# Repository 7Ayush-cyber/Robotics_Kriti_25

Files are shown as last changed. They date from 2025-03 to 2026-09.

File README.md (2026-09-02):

# Smart Disposable Dustbin — Robotics Kriti '25 🏆

**Gold Medal Winner, Kriti (Robotics Competition), 2025**

An automated waste management system that combines sensor-based waste segregation, vacuum-powered plastic bag deployment, and CNC-controlled mechanisms to make waste disposal more efficient, hygienic, and hands-free.

## Overview

The Smart Disposable Dustbin automates the full waste-handling cycle — detecting waste, opening the lid, segregating it, compacting it, and deploying a fresh plastic liner — with minimal manual intervention. The system integrates ultrasonic distance/level sensing, gas sensing, a BLDC fan for vacuum-based bag handling, and a stepper-motor-driven CNC mechanism, all coordinated through an Arduino Mega.

## Key Features

- **Automatic lid operation** — opens/closes based on proximity detection, reducing manual contact and improving hygiene
- **Sensor-based level detection** — ultrasonic sensors monitor fill level to know when the bin needs attention
- **Gas sensing** — detects buildup of harmful/foul gases inside the bin
- **Vacuum-powered bag deployment** — a BLDC fan is used to unfurl and seat a new plastic bag automatically after disposal
- **CNC-controlled compaction mechanism** — a stepper-motor-driven system compacts waste and manages the mechanical sequencing of the bin
- **Reduced manual effort** — minimizes the need for a person to touch the bin, its lid, or the liner

## Repository Contents

| Category | Files |
|---|---|
| **Firmware (Arduino)** | `MainMega.ino` (main controller), `sensors.ino`, `lid_opening.ino`, `New_bag_deployment.ino`, `Level_Detection_CNC.ino` |
| **CAD Assemblies** | `Assem1.SLDASM`, `dustbin.SLDASM`, `dustbin_2.SLDASM`, `Plastic_wrapper_assembly.SLDASM` |
| **CAD Parts** | Individual `.SLDPRT` files for structural components — walls, base, lid, motor mounts, compactor walls, plastic holder/wrapper parts, etc. |
| **Engineering Drawings** | `.SLDDRW` drawing files with corresponding `.DXF` exports for manufacturing/laser-cutting |
| **Sheet Metal Data** | `.yld` files (SolidWorks sheet metal flat-pattern data) |
| **Reports** | `Report_Smart_disposable_dustbin.pdf`, `robotics_kriti_final_report.pdf` |

## Hardware Used

- Arduino Mega (main controller)
- Ultrasonic sensors (level/proximity detection)
- Gas sensor
- BLDC fan (vacuum-powered bag deployment)
- Stepper motor (CNC-controlled compaction/actuation)

## Getting Started

### Mechanical
1. Open the assembly files (`Assem1.SLDASM`, `dustbin.SLDASM`, etc.) in SolidWorks to review the full CAD model.
2. Use the corresponding `.DXF` files to laser-cut or CNC-machine the sheet metal/plastic parts.
3. Assemble per the drawings in the `.SLDDRW` files.

### Electronics / Firmware
1. Wire the ultrasonic sensors, gas sensor, BLDC fan, and stepper motor to the Arduino Mega as referenced in the `.ino` files.
2. Upload `MainMega.ino` as the primary control program (it coordinates the subsystem logic found in `sensors.ino`, `lid_opening.ino`, `New_bag_deployment.ino`, and `Level_Detection_CNC.ino`).
3. Power on and test each subsystem (lid actuation, level detection, bag deployment) individually before full integration.

## Documentation

For the complete design rationale, methodology, and results, see:
- `Report_Smart_disposable_dustbin.pdf`
- `robotics_kriti_final_report.pdf`

## Acknowledgment

This project was built for **Kriti**, where it won the **Gold Medal**. This repository is forked from [7Ayush-cyber/Robotics_Kriti_25](https://github.com/7Ayush-cyber/Robotics_Kriti_25).

## License

No license file is currently included. Add one (e.g., MIT) if you intend for others to reuse this work.

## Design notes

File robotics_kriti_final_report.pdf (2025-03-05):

# Smart Disposal Machine

## Organizer: Robotics Club

## Kriti 2025

# Final Submission Report

# ____________________________________

Smart Disposal Machine

## Contents:

1 Abstract | 2
2 Problem Understanding | 2
3 Approach | 3
3.1 Electronics | 3
3.1.1 Lid opening | 3
3.1.2 New bag deployment | 3
3.1.3 Sealing mechanism | 4
3.1.4 Waste classification | 4
3.2 Arduino Code | 4
3.2.1 Lid opening | 4
3.2.2 New bag deployment | 5
3.2.3 Sealing element | 5
3.2.4 Level detection and stepper motor | 5
3.3 Chassis and Dimensions | 6
4 Future Scopes and Applications | 8
4.1 Integration with AI for Smart Waste | 8
4.2 IoT-Enabled Data Analytics and Smart City Integration | 8
4.3 Solar-Powered Operation for Sustainability | 8
4.4 Industrial and Commercial Applications | 8
4.5 Public Awareness and Incentive-Based | 8
4.6 Robotic Waste Handling and Automation | 8
4.7 Accessibility for People with Disabilities | 8
5 Results and Conclusion | 9
References | 10

## 1 Abstract

This project introduces a Smart Disposal Machine (SDM), an advanced waste management system designed for real-time waste monitoring and efficient disposal operations. The SDM utilizes sensor-based detection to continuously track waste levels, allowing for optimized collection schedules. This helps prevent bin overflow, which can lead to unsanitary conditions, unpleasant odours, and increased maintenance efforts. By ensuring timely waste collection, the system significantly enhances hygienic operations, particularly in high-traffic environments such as public spaces, offices, and commercial facilities.

The SDM is equipped with automated mechanical systems that reduce the need for frequent manual intervention. These mechanisms allow for longer operational uptime, decreasing labour requirements and improving overall efficiency. For advanced functionality, IoT integration enables remote
monitoring | and | automation, | allowing | waste
management personnel to receive real-time data on waste levels and system status. This feature enhances efficiency by facilitating predictive maintenance and timely waste disposal, reducing operational costs and response times.

Additionally, the system can incorporate automated waste segregation, streamlining the recycling process by categorizing waste into different types, such as biodegradable and non-biodegradable materials. By addressing key inefficiencies found in traditional waste disposal methods—such as irregular waste collection, inefficient bin usage, and lack of real-time monitoring—the SDM offers a cleaner, more sustainable approach to waste management. This makes it an ideal solution for high-footfall environments where effective waste disposal is crucial for maintaining cleanliness and public health.

## 2 Problem Understanding

- Smart Waste Monitoring System:

The system is designed to continuously track and monitor waste levels in real-

time, | ensuring | that | waste | collection
schedules are optimized based on actual bin capacity. This prevents waste overflow, which can lead to hygiene issues, operational inefficiencies, and unnecessary collection efforts. By prioritizing waste disposal in high-traffic areas, this system enhances public
sanitation | and | resource | allocation,
reducing costs associated with inefficient waste collection.
- Hygienic and Efficient Waste Disposal:

The solution aims to minimize human exposure to unsanitary conditions by automating waste collection and disposal
processes. | By | integrating | touch-free
mechanisms and reducing direct interaction with waste, the system ensures safer disposal operations, particularly in areas prone to contamination, such as hospitals, food courts, and public spaces. Additionally, the system's efficiency reduces the frequency of required maintenance, making it more cost-effective and sustainable over time.
- IoT-Enabled Automation:

The incorporation of Internet of Things (IoT) technology allows for remote
monitoring, | automated | alerts, | and
predictive maintenance, reducing reliance on manual checks. By providing real-time waste level updates, the system ensures timely intervention before bins reach capacity.
Automated | notifications | improve
operational efficiency by alerting waste management personnel about full bins enabling proactive waste collection and maintenance scheduling.
- Automated Waste Segregation:

The system is designed to intelligently
classify | waste | into | biodegradable,
recyclable, | and | non-recyclable
categories, reducing the burden of manual sorting. This feature enhances recycling efficiency, ensures proper disposal of
different | waste | types, | and | supports
environmental sustainability initiatives. By automating segregation, the system promotes a more streamlined and eco-friendly waste management approach, minimizing landfill waste and optimizing resource recovery.

Each of these components contributes to a robust, scalable, and intelligent waste management system, aiming to improve sanitation, efficiency, and sustainability in high-footfall environments. The integration of smart monitoring, automation, and waste segregation ensures that waste disposal is not only more efficient but also more environmentally responsible.

## 3 Approach

In this section, we outline the approach adopted for developing the Smart Disposal Machine (SDM) to enhance waste management efficiency and hygiene. We begin by describing the ultrasonic sensor-based waste level monitoring system, which categorizes fill levels at 33%, 66%, and 100% indicated by LEDs and provides real-time notifications through a web application. This is followed by an overview of the automatic lid mechanism, which utilizes ultrasonic sensors to minimize human exposure and maintain hygiene. Additionally, an automatic sealing mechanism is implemented to prevent waste exposure. To enhance waste classification, methane and alcohol sensors are incorporated to differentiate between biodegradable and non-biodegradable waste before disposal. Furthermore, an automated bag deployment system is integrated, where a vacuum exhaust fan deploys the new cut bag once the sealing is executed and filled bag is removed. This integrated approach ensures efficient waste management, improved sanitation, and enhanced automation. Following is the

### 3.1 Electronics

This system incorporates a total of three microcontroller boards to manage various functions. An Arduino Uno is responsible for hand detection, lid operation, and new bag deployment via the exhaust mechanism. An Arduino Mega 2560 controls the sealing mechanism and level detection, while a NodeMCU is integrated for IoT connectivity.

### 3.1.1 Lid opening:

The lid opens in response to an ultrasonic sensor that detects hand proximity and is actuated by a TowerPro MG90S micro servo motor. Once triggered, the lid remains open for a predetermined duration, allowing sufficient time for trash disposal before automatically closing. Safety measures ensure that the lid does not close abruptly, preventing accidental obstructions or injuries.

### 3.1.2 New bag deployment:

A new bag is deployed using a vacuum mechanism that relies on an exhaust fan powered by an EMAX 1400KV BLDC motor, which is switch-operated. The exhaust is strategically positioned at the bottom corner inside a housing, ensuring efficient suction. The fan generates a controlled vacuum force, which is strong enough to pull the plastic bag just enough to prepare it for the next filling cycle without causing excessive stretching or misalignment.

The system uses a single large garbage bag (refer [1]) as a continuous material source for multiple refills. Instead of using pre-cut individual bags, the large bag remains folded or loosely arranged within the housing. As each sealing and cutting cycle is completed, the vacuum mechanism pulls the next section of the bag forward, ensuring that a fresh portion is available for the next filling operation. This process allows the bottom of the newly deployed bag to be sealed simultaneously while the top of the filled bag is cut off. The vacuum ensures that the plastic bag is smoothly positioned before filling, preventing wrinkles or improper alignment. Once the new section of the bag is in place, the vacuum mechanism disengages, allowing the system to proceed with the next cycle seamlessly.

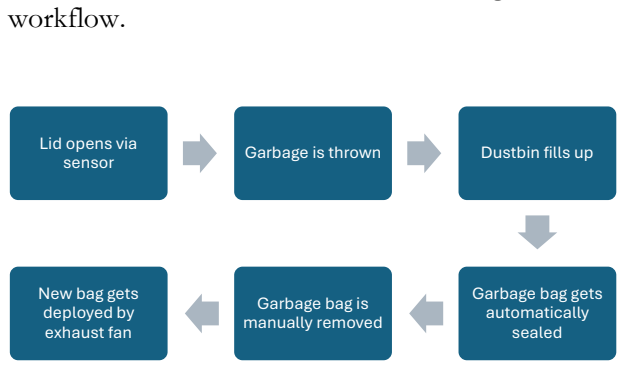
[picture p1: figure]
workflow.; Lid opens via sensor; Garbage is thrown; Dustbin fills up; Garbage bag gets automatically sealed; Garbage bag is manually removed; New bag gets deployed by exhaust fan

### 3.1.3 Sealing mechanism:

The sealing process is achieved using a single-axis mechanism designed for precise linear motion. A nichrome sealing element, fixed on one side, is responsible for simultaneously sealing and cutting plastic bags, like a plastic bag sealing machine. The system employs a lead screw mechanism, driven by an RMCS 1023 stepper motor, to control movement along a single axis. A prismatic joint guides this motion, ensuring accuracy and repeatability. (refer [2])

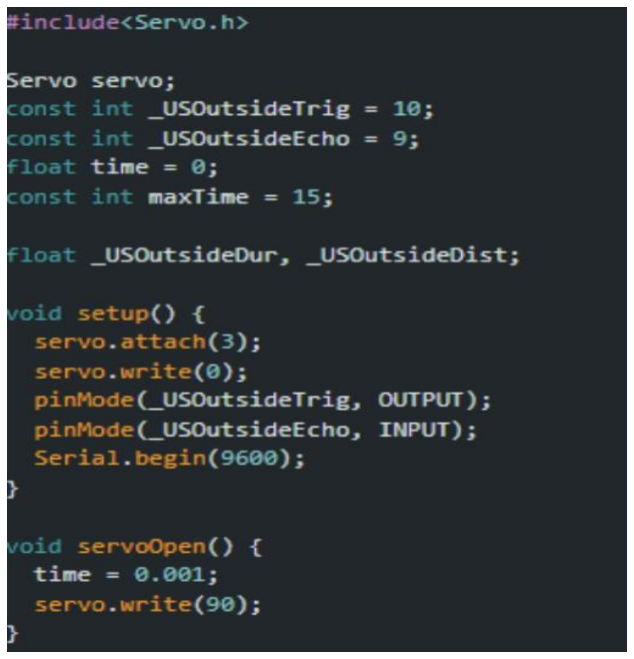
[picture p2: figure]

A rod, rigidly attached to the nut of the lead screw, serves as the actuator that pulls the plastic bag toward the sealing element. As the bag reaches the sealing position, the heated nichrome wire seals the top of the filled bag while simultaneously cutting and sealing the bottom of the next bag, ensuring a continuous and efficient sealing process(refer [1],[3]). Once sealing is complete, the actuator retracts to its home position, ready for the next cycle. A relay controls the activation of the sealing element, and the entire system operates using a LiPo battery for power.

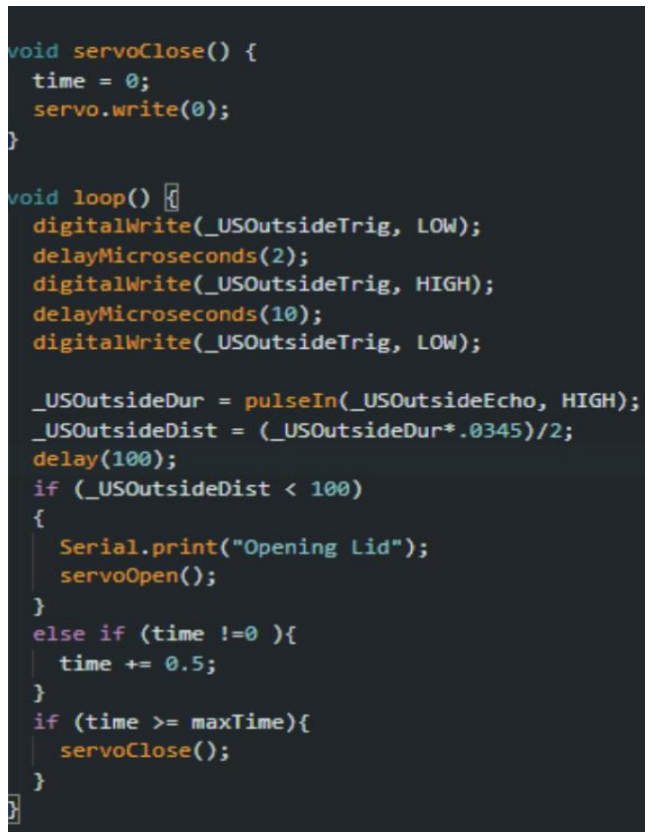
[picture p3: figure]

### 3.1.4 Waste classification:

Alcohol and methane sensors will be integrated into the system and positioned near the waste disposal opening to classify waste as either biodegradable or non-biodegradable before disposal. As waste is introduced, the sensors detect the presence of specific gases, such as methane and
alcohol | vapours, | which | indicate | organic
decomposition. If the detected gases exceed a predefined threshold, the waste is classified as biodegradable; otherwise, it is categorized as non-biodegradable.

To provide immediate feedback to users, an LED indicator will blink according to the classification of the waste. Different blinking patterns or colours can be used to distinguish between biodegradable and non-biodegradable waste, ensuring clear and intuitive identification. This visual indication helps guide users in placing waste correctly, reducing misclassification. The sensor placement near the opening ensures that classification occurs before disposal, minimizing errors and improving accuracy. The entire process is automated, eliminating the need for manual sorting at the point of disposal.

### 3.2 Arduino Code

Following are the code snippets of every mechanism:

### 3.2.1 Lid opening:

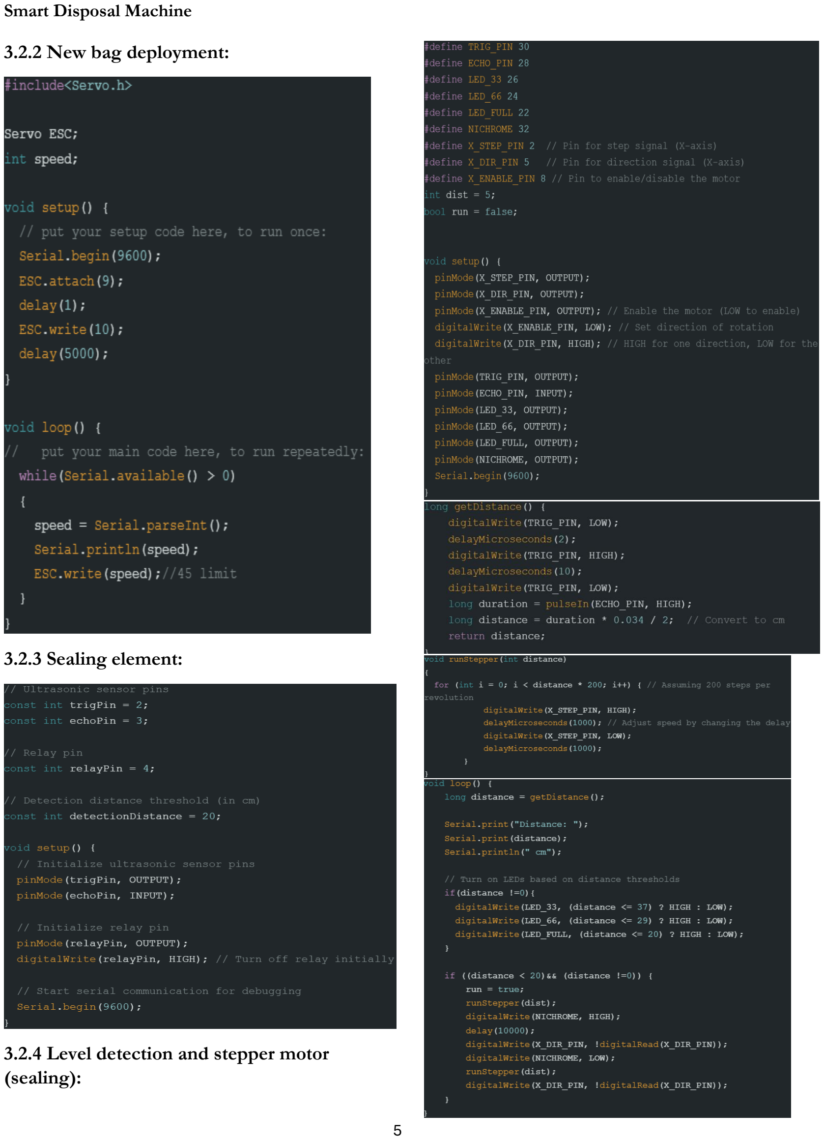
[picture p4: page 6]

### 3.2.2 New bag deployment:

### 3.2.3 Sealing element:

### 3.2.4 Level detection and stepper motor

(sealing):

### 3.3 Chassis and dimensions

The chassis of the bin has been meticulously designed using 4mm thick acrylic sheet cutouts, ensuring a lightweight yet robust structure. The entire assembly is precisely engineered to fit within a compact 45 × 45 × 45 mm volume, optimizing space efficiency while maintaining structural integrity. Within this framework, the storage compartment is allocated a dedicated volume of 25 × 25 × 25 mm, allowing for efficient containment and management of waste.

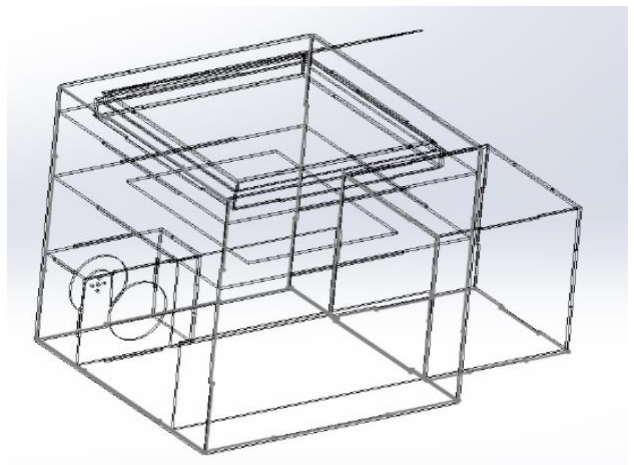
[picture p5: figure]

The system's component arrangement follows a hierarchical order from top to bottom, ensuring smooth operation and accessibility. The sequence of placements is as follows:

1. Lid Opening Mechanism: Positioned at the topmost layer, this mechanism facilitates automated or manual opening of the bin lid, ensuring ease of waste disposal.
2. Bag Refill System: Directly beneath the lid opening mechanism, the bag refill system allows for seamless waste bag replacement,
ensuring | continuous | usability | without
manual intervention.

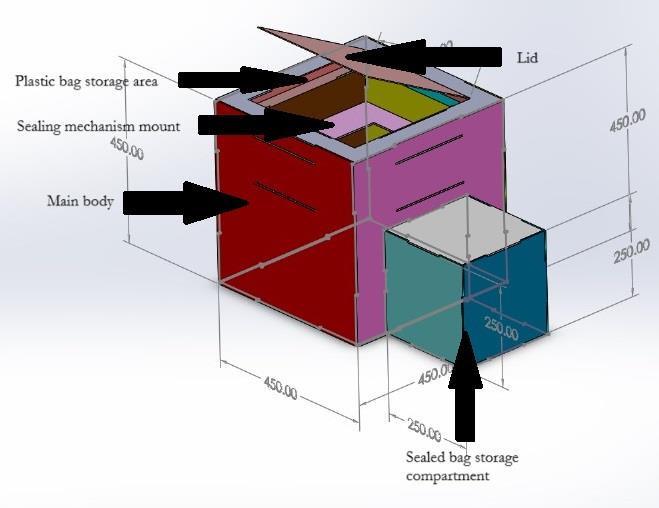
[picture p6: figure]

3. Sealing Mechanism: This module is responsible for securely sealing the waste bag after disposal, preventing leakage and maintaining hygiene within the storage compartment.
4. Vacuum Exhaust Fan: To optimize space utilization and maintain internal air pressure, a vacuum exhaust fan is incorporated below the sealing mechanism. This component aids in the removal of excess air, facilitating a compact and efficient waste management process.
5. Storage Compartment: The final section houses the storage area where sealed waste is accumulated. The storage design ensures optimal space utilization while maintaining stability and accessibility.

The entire design process was executed using
SolidWorks | 2024, | leveraging | its | advanced
parametric modelling to refine the structural and functional aspects of the bin. The software facilitated precise geometric modelling, component alignment, and stress analysis, ensuring that the final design
adheres | to | durability | and | manufacturability
constraints.

To further illustrate the spatial configuration and component integration, the following technical diagrams provide multi-view representations of the geometry and internal structure of the bin. These
diagrams | serve | to | highlight | key | design
considerations, | including | component | fitment,
structural stability, and operational workflow.

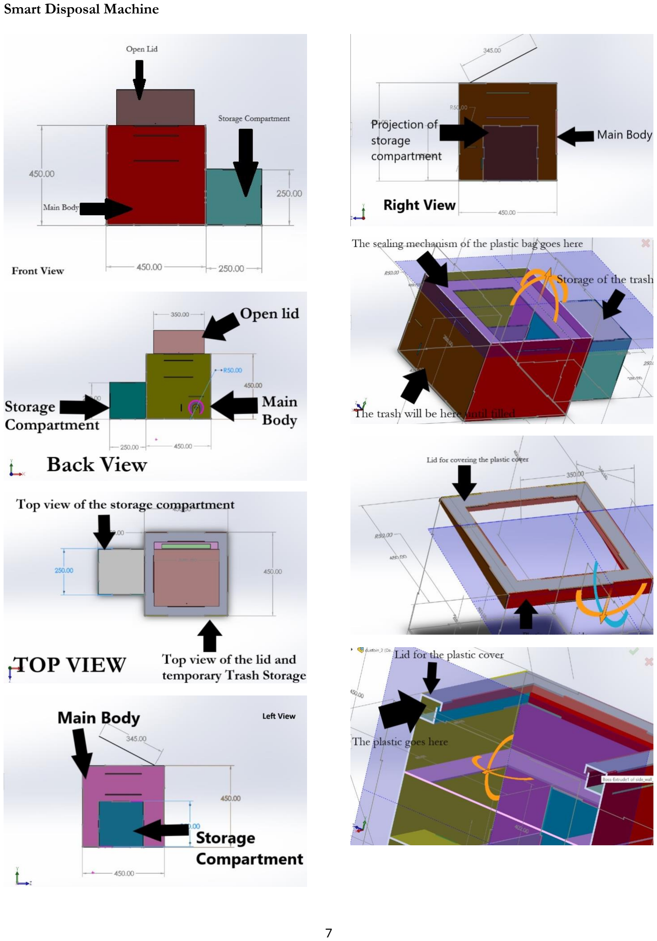
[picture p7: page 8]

## 4 Future Scopes and Applications

The Smart Disposal Machine (SDM) has the
potential | for | significant | advancements | and
widespread applications in various sectors. Future enhancements and potential applications include:

### 4.1 Integration with AI for Smart Waste

Sorting: By incorporating artificial intelligence and machine learning, the SDM could autonomously classify waste with greater accuracy. Using computer vision and advanced sensor fusion, the system could
distinguish | between | different | categories | of
biodegradable and non-biodegradable materials. This would enhance automated sorting, ensuring that recyclable, organic, and general waste are processed more efficiently. AI-driven classification could also adapt over time, improving sorting accuracy based on collected data and reducing errors in waste segregation.

### 4.2 IoT-Enabled Data Analytics and Smart

City Integration: The SDM can be integrated with cloud-based IoT platforms, enabling real-time monitoring of waste levels and predictive analytics for better resource management. This would allow municipalities and waste collection agencies to optimize garbage collection routes, minimizing fuel consumption and operational costs. Real-time data can be used to predict peak waste disposal time
and | adjust | collection | schedules | accordingly,
preventing bin overflow. Additionally, SDMs across a city could be networked into a smart city infrastructure, where centralized monitoring helps enhance urban waste management strategies.
4.3 | Solar-Powered | Operation | for
Sustainability: To reduce dependence on external power sources, future SDM models could be equipped with solar panels for self-sustained operation. This would be particularly beneficial in remote areas, public parks, and off-grid locations, where conventional power sources may not be readily available. Solar integration would enhance energy efficiency, allowing the SDM to operate with minimal environmental impact while ensuring uninterrupted functionality even during power outages.

### 4.4 Industrial and Commercial Applications:

The SDM could be deployed in high-footfall locations such as hospitals, malls, airports, and office buildings, where efficient waste management is crucial. By automating waste disposal, it can help reduce labour requirements and improve hygiene in areas where large amounts of waste are generated daily. Additionally, in industrial settings, the SDM could be programmed to segregate hazardous and non-hazardous waste, ensuring
compliance | with | safety | and | environmental
regulations. This would streamline waste processing in factories, laboratories, and medical facilities, where improper disposal can pose risks.

### 4.5 Public Awareness and Incentive-Based

Recycling: A future version of the SDM could incorporate an incentive system to encourage responsible waste disposal. Users could be rewarded with credits, coupons, or discounts for properly sorting their waste into the correct disposal sections. This feature could be particularly effective in commercial areas, schools, and public spaces, promoting better waste segregation habits and increasing recycling rates. By providing immediate feedback on correct disposal behaviour, the system could also serve as an educational tool for communities.

4.6 | Robotic | Waste | Handling | and
Automation: Integrating robotic arms | or
conveyor-based | mechanisms | could | further
enhance automation in waste handling. These features would enable precise waste placement, compression, and movement within the disposal unit, minimizing human intervention. For large-scale waste management, robotic sorting could improve efficiency by handling bulky or irregularly shaped waste items that conventional sorting mechanisms struggle with. Additionally, automation could enhance the processing of recyclable materials, separating them more effectively for reuse.

### 4.7 Accessibility for People with Disabilities:

To ensure inclusive and user-friendly waste disposal, the SDM could be designed with accessibility features such as voice command activation, motion sensors, and automated waste dispensing. These features would assist individuals with disabilities, making it easier for them to dispose of waste without requiring physical effort. Additional improvements, such as adjustable height settings and Braille-based instructions, could further enhance usability for a wider range of users, ensuring that the system is adaptable to diverse accessibility needs.

By implementing these advancements, the Smart Disposal Machine (SDM) can become a more efficient, technologically advanced, and scalable waste management solution, addressing key challenges in waste disposal while adapting to various urban and industrial needs.

## 5 Results and Conclusions

The development of the Smart Disposal Machine (SDM) resulted in a functional prototype, demonstrating the feasibility of automated waste management. The system successfully integrates ultrasonic sensor-based waste level monitoring, categorizing fill levels at 33%, 66%, and 100%, with real-time notifications sent through a web application. This feature allows users or waste management personnel to track bin capacity
remotely, | reducing | the | need | for | manual
inspections.
The | prototype | includes | an | automatic | lid
mechanism, which operates via an ultrasonic sensor and a TowerPro MG90S micro servo motor. This minimizes direct human contact with waste, improving hygiene and reducing the risk of contamination. Additionally, methane and alcohol sensors classify waste into biodegradable and non-biodegradable categories before disposal. An LED indicator provides real-time feedback to users, ensuring proper segregation at the point of disposal.

A key feature of the SDM prototype is its automated waste sealing and bag deployment mechanism.

Once the bin reaches full capacity, the system initiates a sealing process using a nichrome sealing element and a lead screw-driven actuator. The filled bag is sealed and separated, while a vacuum-based mechanism ensures that a new section of the garbage bag is deployed for the next cycle. This
automation | reduces | manual | intervention,
enhancing efficiency and making waste disposal more streamlined.

However, as a prototype, the SDM is still in its early development stages and may not function flawlessly in all scenarios. Certain mechanical, electronic, or environmental factors could lead to occasional inconsistencies in waste detection, sealing, or sorting. Factors such as sensor calibration, bag alignment, and power fluctuations could affect
performance, | highlighting | areas | for | further
refinement.

While this version serves as a proof of concept, there is significant potential for improvement. Future advancements could include AI-driven waste sorting, IoT-based data analytics, and expanded automation features to enhance accuracy, efficiency, and scalability. With continued development, the SDM has the potential to evolve into a reliable, fully automated waste management solution, capable of addressing inefficiencies in modern waste disposal systems.

## References

[1] Research paper/Patent: https://ppubs.uspto.gov/dirsearch-public/print/downloadBasicPdf/20240327111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 YjdiYi0xODE3NDBmODBhYzEiLCJ2ZXIiOiIyYzc0N2U3ZC0wY2UzLTRiZDItOTFkYi01NDA2NDY5M Tk2MWUiLCJleHAiOjB9 (https://ppubs.uspto.gov/dirsearch-public/print/downloadBasicPdf/20240327111)
[2] Video 1: https://youtu.be/5tFnOZyDE_Q?si=TQ6Yb1H6t06FDDJ1
[3] Video 2: https://youtu.be/1gI3jva89lk?si=dEMHP1La-I92vb21

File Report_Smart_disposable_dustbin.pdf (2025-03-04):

# Smart Disposal Machine

## Organizer: Robotics Club

## Kriti 2025

# Final Submission Report

# ____________________________________

Smart Disposal Machine

## Contents:

1 Abstract | 2
2 Problem Understanding | 2
3 Approach | 2
3.1 Electronics | 2
3.1.1 Lid opening | 2
3.1.2 New bag deployment | 2
3.1.3 Sealing mechanism | 3
3.1.4 Waste classification | 3
3.2 Arduino Code | 3
3.2.1 Lid opening | 3
3.2.2 New bag deployment | 3
3.2.3 Sealing element | 4
3.2.4 Level detection and stepper motor | 4
3.3 Chassis and Dimensions | 4
4 Future Scopes and Applications | 5
4.1 Integration with AI for Smart Waste | 5
4.2 IoT-Enabled Data Analytics and Smart City Integration | 5
4.3 Solar-Powered Operation for Sustainability | 5
4.4 Industrial and Commercial Applications | 5
4.5 Public Awareness and Incentive-Based | 5
4.6 Robotic Waste Handling and Automation | 5
4.7 Accessibility for People with Disabilities | 5
5 Results and Conclusion | 5
References | 6

## 1 Abstract

This project introduces a Smart Disposal Machine (SDM) designed for real-time waste monitoring and efficient waste management. Utilizing sensor-based detection, the system optimizes trash collection schedules, minimizing overflow and ensuring hygienic operations. Advanced mechanisms extend operational time by reducing the frequency of manual interventions. Optional IoT integration enables remote monitoring and automation, enhancing efficiency. Additionally, the system can incorporate automated waste segregation to streamline recycling. By addressing key inefficiencies in traditional waste disposal, the SDM promotes a cleaner and more sustainable waste management approach in hightraffic environments.

## 2 Problem Understanding

- Smart Waste Monitoring System: Develop a system that continuously monitors waste levels in real-time to optimize collection schedules and prevent overflow in hightraffic areas.
- Hygienic and Efficient Waste Disposal: Design a solution that minimizes human exposure to unsanitary waste conditions during disposal and maintenance.
- IoT-Enabled Automation: Incorporate remote monitoring and automated alerts to enhance operational efficiency and minimize manual intervention.
- Automated Waste Segregation: Develop an intelligent system to classify waste into biodegradable, recyclable, and non-recyclable categories.

Each of these components contributes to a robust and scalable waste management system aimed at improving sanitation, efficiency, and sustainability.

## 3 Approach

In this section, we outline the approach adopted for developing the Smart Disposal Machine (SDM) to enhance waste management efficiency and hygiene. We begin by describing the ultrasonic sensor-based waste level monitoring system, which categorizes fill levels at 33%, 66%, and 100% and provides real-time notifications through a web application. This is followed by an overview of the automatic lid mechanism, which utilizes ultrasonic sensors to minimize human exposure and maintain hygiene. Additionally, an automatic sealing mechanism is implemented to prevent waste exposure. To enhance waste classification, methane and alcohol sensors are incorporated to differentiate between biodegradable and non-biodegradable waste before disposal. Furthermore, an automated bag deployment system is integrated, where a vacuum exhaust fan deploys a new bag once the previous one is sealed and removed. This integrated approach ensures efficient waste management, improved sanitation, and enhanced automation. Following is the workflow.

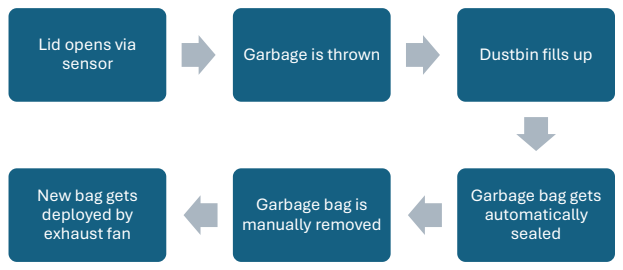
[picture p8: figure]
Lid opens via sensor; Garbage is thrown; Dustbin fills up; Garbage bag gets automatically sealed; Garbage bag is manually removed; New bag gets deployed by exhaust fan

### 3.1 Electronics

This system incorporates a total of three microcontroller boards to manage various functions. An Arduino Uno is responsible for hand detection, lid operation, and new bag deployment via the exhaust mechanism. An Arduino Mega 2560 controls the sealing mechanism and level detection, while a NodeMCU is integrated for IoT connectivity.

### 3.1.1 Lid opening:

The lid opens in response to an ultrasonic sensor which detects hand proximity and is actuated by a TowerPro MG90S micro servo motor.

### 3.1.2 New bag deployment:

A new bag is deployed using a vacuum mechanism powered by an exhaust fan, which is driven by an EMAX 1400KV BLDC motor which is switch operated. A big single piece garbage bag is used for multiple refills.

### 3.1.3 Sealing mechanism:

For the sealing process, a nichrome sealing element, fixed on one side, is utilized. A rod, connected to a prismatic joint driven by a lead screw powered by an RMCS 1023 stepper motor, pulls the filled bag toward the sealing element, facilitating both sealing and cutting. A relay will be used for the switching mechanism, and the entire system is powered by a LiPo battery.

### 3.1.4 Waste classification:

Alcohol and methane sensors will be integrated into the system to classify waste as either biodegradable
or | non-biodegradable | before | disposal. | This
classification ensures that users can dispose of waste appropriately based on its composition, promoting efficient waste segregation and management.

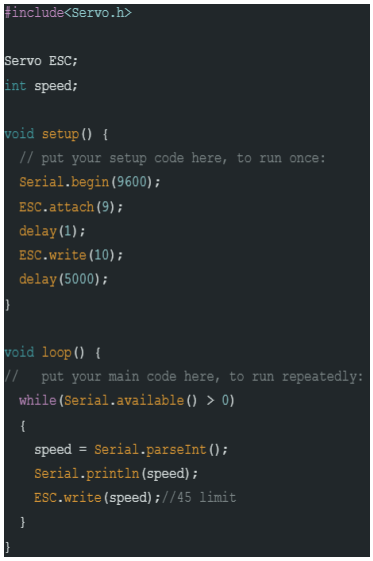
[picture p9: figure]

### 3.2 Arduino Code

Following are the code snippets of every mechanism:

### 3.2.1 Lid opening:

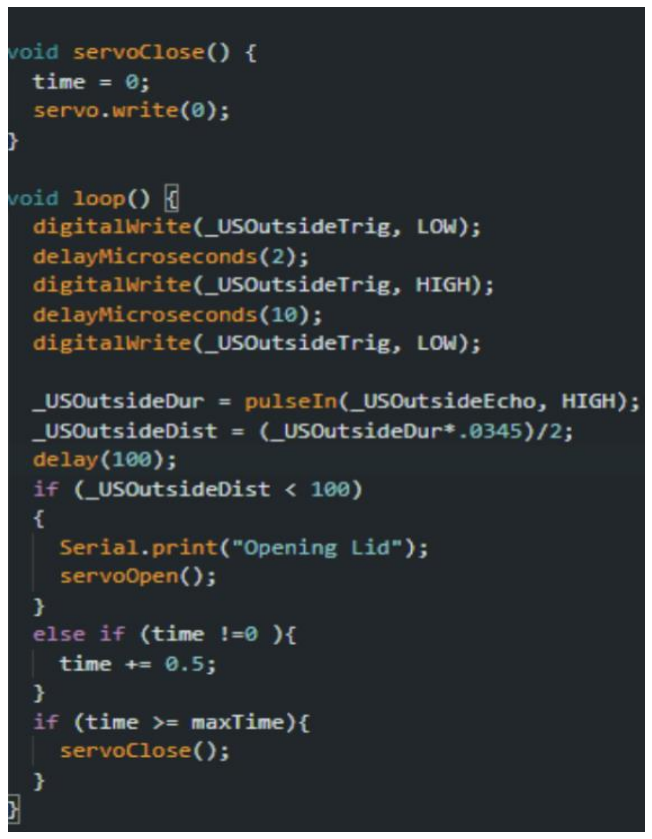
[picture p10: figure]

### 3.2.2 New bag deployment:

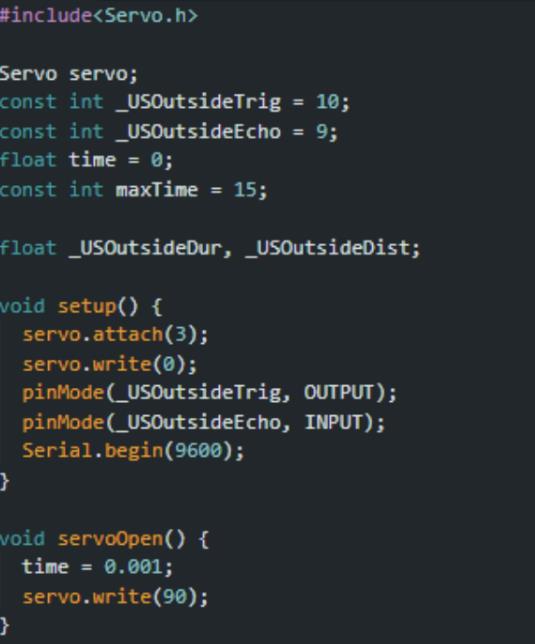
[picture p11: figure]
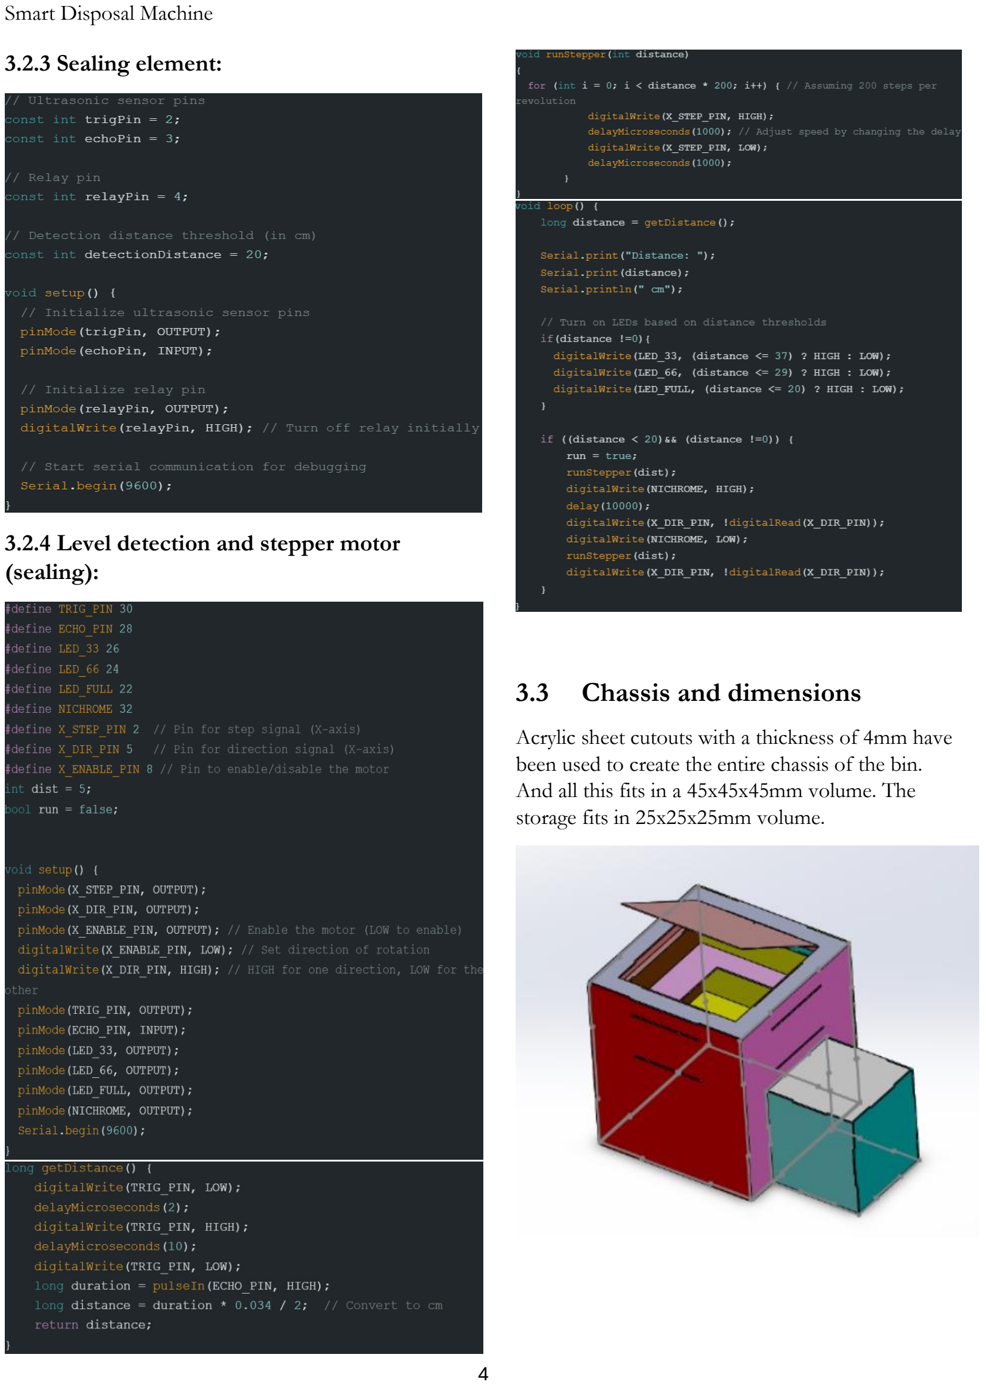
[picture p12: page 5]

### 3.2.3 Sealing element:

### 3.2.4 Level detection and stepper motor

(sealing):

### 3.3 Chassis and dimensions

Acrylic sheet cutouts with a thickness of 4mm have been used to create the entire chassis of the bin. And all this fits in a 45x45x45mm volume. The storage fits in 25x25x25mm volume.

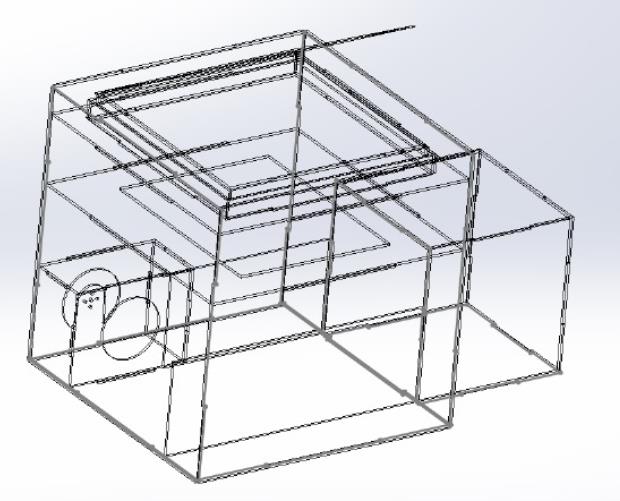
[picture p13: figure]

## 4 Future Scopes and Applications

The Smart Disposal Machine (SDM) has the
potential | for | significant | advancements | and
widespread applications in various sectors. Future enhancements and potential applications include:

### 4.1 Integration with AI for Smart Waste

Sorting: By incorporating artificial intelligence and machine learning, the SDM could autonomously classify waste more accurately, distinguishing between different types of biodegradable and non-biodegradable materials for optimized recycling and waste processing.

### 4.2 IoT-Enabled Data Analytics and Smart

City Integration: The SDM can be connected to cloud-based IoT platforms, allowing real-time waste monitoring and predictive analytics. This data could help municipalities optimize garbage collection routes, reducing fuel consumption and operational costs while preventing overflow.

4.3 | Solar-Powered | Operation | for
Sustainability: To enhance eco-friendliness, future versions of the SDM could be equipped with solar panels, reducing reliance on external power sources and making the system more sustainable in remote and off-grid areas.

### 4.4 Industrial and Commercial Applications:

The SDM can be deployed in hospitals, malls, airports, and office buildings to improve waste management efficiency in high-footfall areas. It can also be used in industrial settings to segregate hazardous and non-hazardous waste.

### 4.5 Public Awareness and Incentive-Based

Recycling: A future version of the SDM could include an incentive system where users are rewarded for responsible waste disposal. This could encourage better waste segregation habits and increase recycling rates.

4.6 | Robotic | Waste | Handling | and
Automation: Integrating robotic arms or conveyor mechanisms could further automate waste handling, reducing human intervention in the disposal and processing stages.

### 4.7 Accessibility for People with Disabilities:

The SDM could be designed with accessibility features such as voice commands, motion sensors, and automated waste disposal mechanisms to assist individuals with disabilities. This would make waste disposal more inclusive and convenient for everyone.

By implementing these advancements, the Smart Disposal Machine can contribute to a more sustainable, efficient, and technologically advanced waste management ecosystem.

## 5 Results and Conclusions

The development of the Smart Disposal Machine (SDM) resulted in a working prototype that demonstrates the feasibility of automated waste management. The system successfully implements ultrasonic sensor-based waste level monitoring, categorizing fill levels at 33%, 66%, and 100%, with real-time notifications through a web application. The automatic lid mechanism minimizes human contact, promoting better hygiene, while the methane and alcohol sensors classify waste into biodegradable and non-biodegradable categories before disposal.

The prototype effectively automates waste disposal by sealing waste and deploying a new bag when the bin reaches full capacity. Through multiple tests, the system has shown that it can streamline waste segregation, reduce manual intervention, and enhance sanitation.

While this version serves as a proof of concept, there is significant potential for further development. Future improvements, such as AI-driven sorting,

IoT-based data analytics, and expanded automation capabilities, could enhance its efficiency and scalability. With continued refinement, the SDM could play a key role in modern waste management, contributing to cleaner and more sustainable environments.

## References

[1] https://ppubs.uspto.gov/dirsearchpublic/print/downloadBasicPdf/20240327111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 YjdiYi0xODE3NDBmODBhYzEiLCJ2ZXIiOiIyYzc0N2U3ZC0wY2UzLTRiZDItOTFkYi01NDA2NDY5M Tk2MWUiLCJleHAiOjB9 (https://ppubs.uspto.gov/dirsearch-public/print/downloadBasicPdf/20240327111)
[2] https://youtu.be/5tFnOZyDE_Q?si=TQ6Yb1H6t06FDDJ1
[3] https://youtu.be/vW-OW67hcNQ?si=MEajZLCJ3xpwDdPy

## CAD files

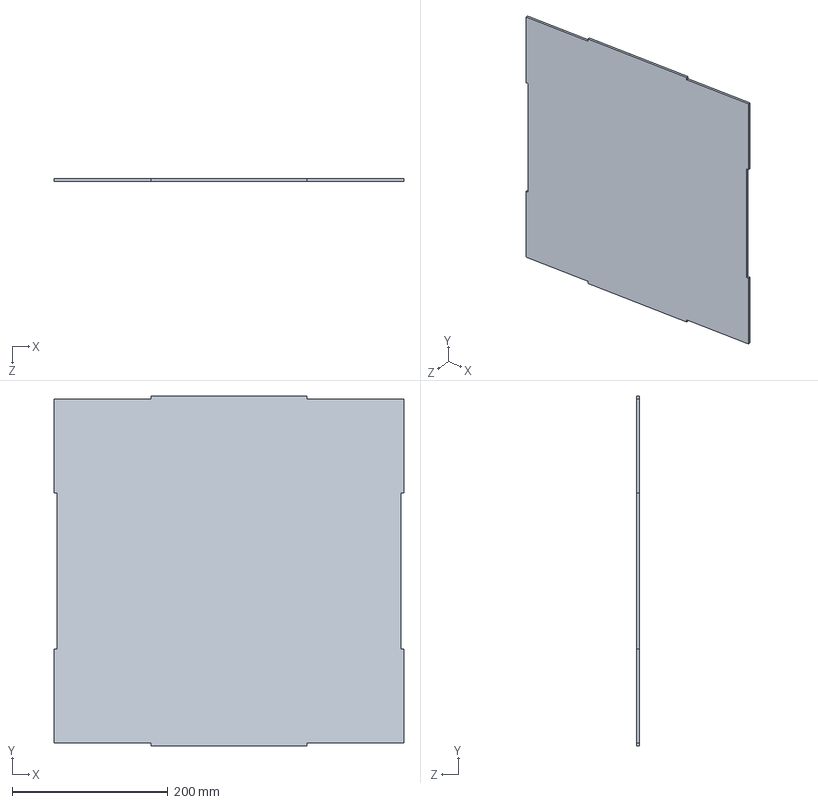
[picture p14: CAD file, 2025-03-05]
front.SLDPRT
450.0 x 450.0 x 4.00 mm

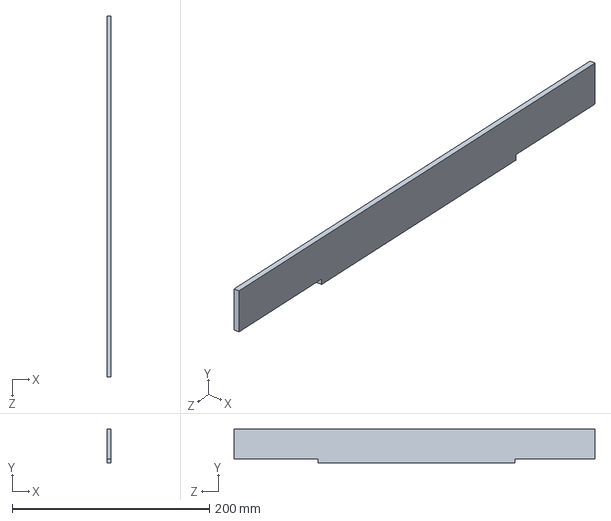
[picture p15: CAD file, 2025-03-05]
plastic_wall_3.SLDPRT
4.00 x 34.0 x 366.0 mm

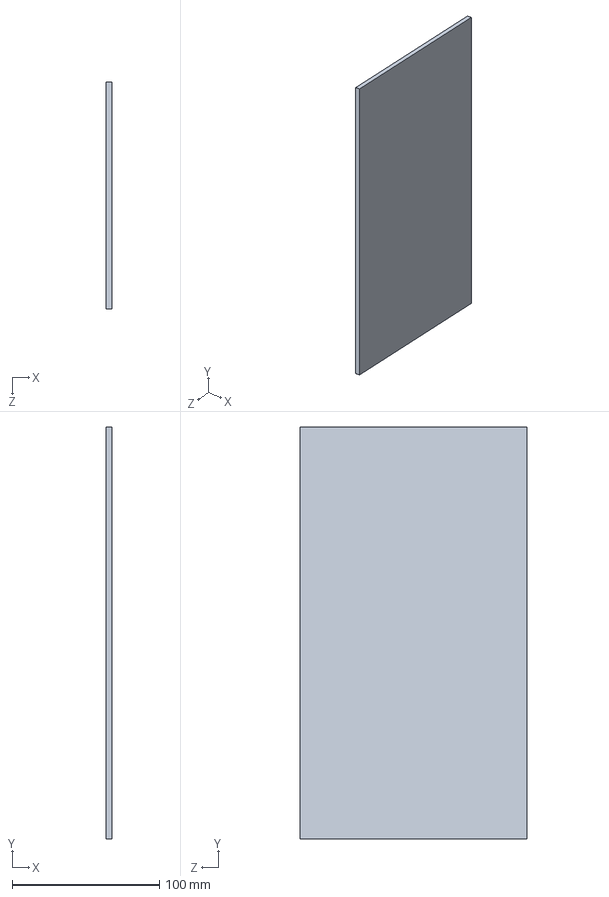
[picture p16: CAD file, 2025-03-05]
compactor_wall_2.SLDPRT
4.00 x 280.0 x 154.0 mm

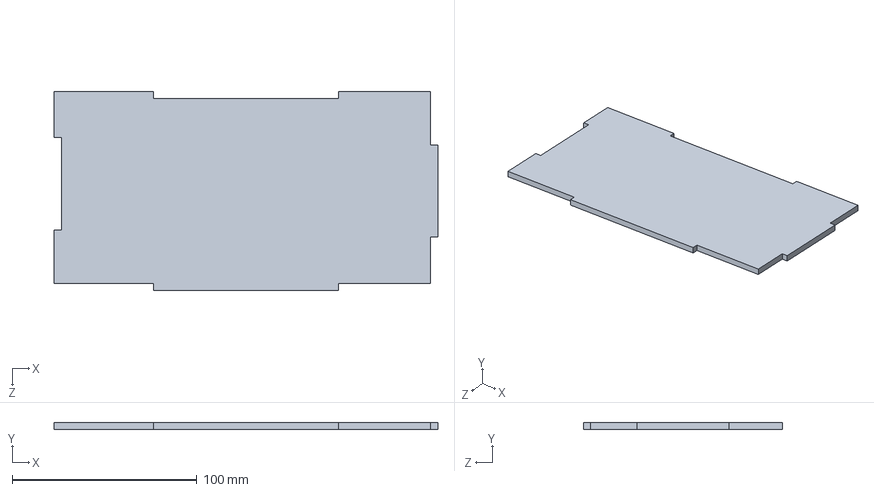
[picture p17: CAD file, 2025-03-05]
motor_roof_2.SLDPRT
208.0 x 4.00 x 108.0 mm

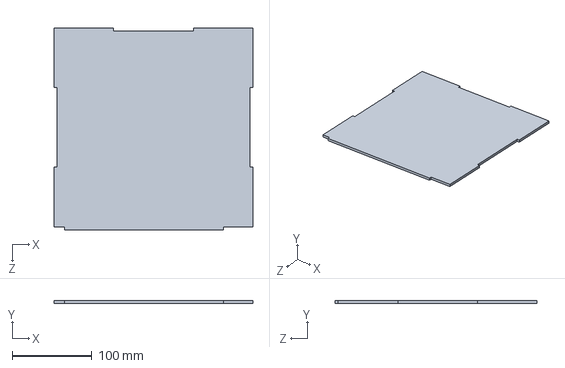
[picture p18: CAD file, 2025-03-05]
storage_base_new.SLDPRT
250.0 x 4.00 x 254.0 mm

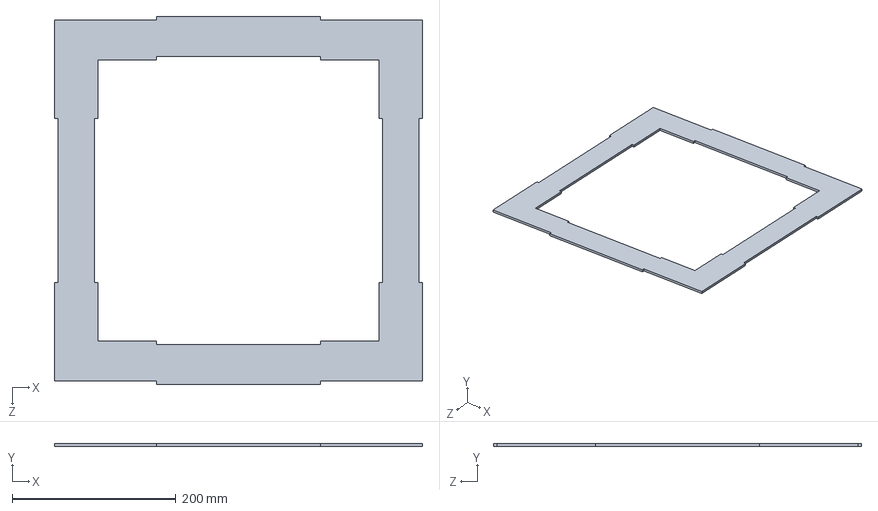
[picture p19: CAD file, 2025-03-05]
plastic_holder_top.SLDPRT
450.0 x 4.00 x 450.0 mm

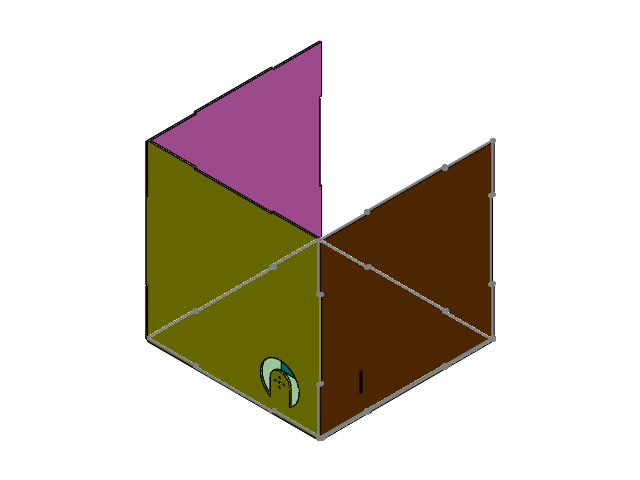
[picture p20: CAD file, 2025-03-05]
Assem1.SLDASM
bottom
Motor_front
motor_base
side_wall
side_wall_2

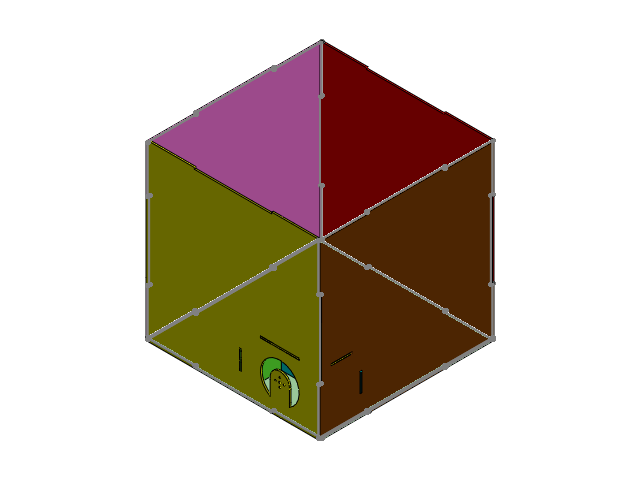
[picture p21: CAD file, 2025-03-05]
dustbin.SLDASM
bottom
Motor_front
motor_base
side_wall
side_wall_2
motor_side
motor_roof_2
front

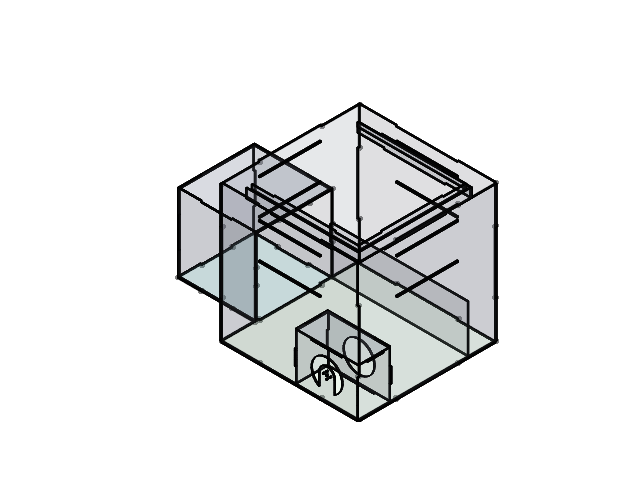
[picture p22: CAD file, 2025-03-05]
dustbin_2.SLDASM
bottom
Motor_front
motor_base
side_wall
side_wall_2
motor_side
motor_roof_2
front
plastic_wall_1
plastic_wall_3
plastic_wall_4
plastic_holder_side_1 x 3
compactor_wall_1
compactor_wall_2
storage_base_new
storage_side_wall1_new
storage_wall2_new
storage_front_new
storage_top_new

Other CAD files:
Plastic_wrapper_assembly.SLDASM
storage_bottom_new.DXF
Draw_16.DXF
Draw_4.DXF
Draw_6.DXF
plastic_wall_2.SLDPRT
Draw_9.DXF
Draw_8.DXF
side_wall_2_part1.DXF
Draw13.SLDDRW
Draw2.SLDDRW
Draw_1.DXF
Draw_1.SLDDRW
Draw_10.DXF
Draw_10.SLDDRW
Draw_11.DXF
Draw_11.SLDDRW
Draw_12.DXF
Draw_12.SLDDRW
Draw_14.DXF
Draw_14.SLDDRW
Draw_15.DXF
Draw_15.SLDDRW
Draw_16.SLDDRW
Draw_17.DXF
Draw_17.SLDDRW
Draw_18.DXF
Draw_18.SLDDRW
Draw_19.DXF
Draw_19.SLDDRW
Draw_2.DXF
Draw_2.SLDDRW
Draw_20.DXF
Draw_20.SLDDRW
Draw_3.DXF
Draw_3.SLDDRW
Draw_4.SLDDRW
Draw_5.DXF
Draw_5.SLDDRW
Draw_6.SLDDRW
Draw_7.DXF
Draw_7.SLDDRW
Draw_8.SLDDRW
Draw_9.SLDDRW
Motor_front.SLDPRT
Part1.SLDPRT
Part2.SLDPRT
bottom.SLDPRT
compactor_wall1.DXF
compactor_wall1.SLDDRW
compactor_wall2.DXF
compactor_wall2.SLDDRW
compactor_wall_1.SLDPRT
electro.DXF
electro.SLDDRW
lid.DXF
lid.SLDDRW
lid.SLDPRT
motor_base.SLDPRT
motor_roof.SLDPRT
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

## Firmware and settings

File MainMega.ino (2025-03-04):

#include<Servo.h>
#include <Arduino.h>

Servo servo;
Servo ESC;

bool isOpen = false;
bool escbool = false;
float time = 0;
const int maxTime = 7;

const int minlvl = 10;
const int sealLoop = 42;
const int pushLoop = 37;

//Part 3 Definition
int lidUltrasonicTrig = 22;
int lidUltrasonicEcho = 23;
int lvlUltrasonicTrig = 24;
int lvlUltrasonicEcho = 25;
int mq3Sensor = 26;
int mq4Sensor = 27;
int relayPin = 28;
int ESCsignal = 29;

int ESCpin = 30;
int lidServo = 53;
int sealingStepperStep = 2;
int sealingStepperDir = 5;
int sealingStepperEnable = 8;
int pushingStepperStep = 3;
int pushingStepperDir = 6;
int pushingStepperEnable = 9;

void servoOpen() {
  time = 0.001;
  Serial.println("Opening the Lid");
  if (!isOpen){
    servo.write(80); // to run continuous Servo Motor <90 pwm runs the motor Clockwise; 0 = max speed
    delay(450);// time delay enough to open the lid 70
    servo.write(90); // 90 pwm to stop the motor
    isOpen = true;
  }
}

void servoClose() {
  time = 0;
  servo.write(100);// >90 pwm to run the motor anticlockwise; 180 = max speed
  delay(450);
  servo.write(90);
  isOpen = false;
}

void runSensors(){
  int alc = digitalRead(mq3Sensor);
  int met = digitalRead(mq4Sensor);
  if (alc > 440){
    //light LED
  }
}

float getDist(int Trig,int Echo){
  digitalWrite(Trig, LOW);
  delayMicroseconds(2);
  digitalWrite(Trig, HIGH);
  delayMicroseconds(10);
  digitalWrite(Trig, LOW);
  float dur = pulseIn(Echo, HIGH);
  float dist = (dur*0.0345) / 2;
  return dist;
}

void runStepper(int step, int distance)
{
  for (int i = 0; i < distance * 200; i++) { // 200 steps per revolution; Number of Revolutions to be calulated
            digitalWrite(step, HIGH);
            delayMicroseconds(1000); // Adjust speed by changing the delay
            digitalWrite(step, LOW);
            delayMicroseconds(1000);
        }
}

void nichrome(){
  Serial.println("Object detected within 20 cm! Turning on relay for 5 seconds.");
  digitalWrite(relayPin, LOW); // Active low signal 
  delay(5000);
  digitalWrite(relayPin, HIGH); // Turn off the relay after 5 seconds
}

void setup() {
  Serial.begin(9600);
  servo.attach(lidServo);//attaching the servo
  servo.write(90);
  pinMode(lidUltrasonicTrig, OUTPUT);
  pinMode(lidUltrasonicEcho, INPUT);
  pinMode(lvlUltrasonicTrig, OUTPUT);
  pinMode(lvlUltrasonicEcho, INPUT);
  pinMode(mq3Sensor, INPUT);
  pinMode(mq4Sensor, INPUT);
  pinMode(relayPin, OUTPUT);
  digitalWrite(relayPin, HIGH); // Turn off relay initially
  pinMode(sealingStepperStep, OUTPUT);
  pinMode(pushingStepperDir, OUTPUT);
  pinMode(sealingStepperEnable, OUTPUT);
  digitalWrite(sealingStepperEnable, LOW);
  digitalWrite(pushingStepperDir, LOW);
  pinMode(ESCsignal, INPUT);
  ESC.attach(ESCpin);
  delay(1);
  ESC.write(20);
  delay(5000);
}

void loop() {
  // put your main code here, to run repeatedly:
  float dist = getDist(lidUltrasonicTrig, lidUltrasonicEcho);
  
  if (dist < 10){
    runSensors();
    servoOpen();
  }
  else if (time !=0 ){
    time += 0.5;
  }
  if (time >= maxTime){
    servoClose();
  }
  float lvlDist = getDist(lvlUltrasonicTrig, lvlUltrasonicEcho);
  if ((lvlDist<22) && (!isOpen) && lvlDist>0){
    Serial.println(lvlDist);
    Serial.print("rine");
    runStepper(sealingStepperStep,sealLoop);
    digitalWrite(relayPin, LOW);
    delay(20000);
    digitalWrite(sealingStepperDir, !digitalRead(sealingStepperDir));
    digitalWrite(relayPin, HIGH);
    runStepper(sealingStepperStep, sealLoop);
    digitalWrite(sealingStepperDir, !digitalRead(sealingStepperDir));
    delay(10000);
    //run relay
    //push
    Serial.println("Running Lower Motor");
    runStepper(pushingStepperStep, pushLoop);
    delay(1000);
    digitalWrite(pushingStepperDir, !digitalRead(pushingStepperDir));
    runStepper(pushingStepperStep, pushLoop);
    digitalWrite(pushingStepperDir, !digitalRead(pushingStepperDir));
    delay(1000);
    Serial.print("RUNNING ESC");
    escbool = false;
  }
  else{
    //Serial.println("No object detected within 20 cm.");
    digitalWrite(relayPin, HIGH); // Turn off the relay
  }
  if (escbool)
  {
    Serial.print("RUNNING ESC");
    delay(7500);
    ESC.write(80);
    delay(6 * 1000);// run fan for 6 secs
    escbool = true;
  }
  else
  {
    ESC.write(20);
  }
}

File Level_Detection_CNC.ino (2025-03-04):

#define TRIG_PIN 30
#define ECHO_PIN 28
#define LED_33 26
#define LED_66 24
#define LED_FULL 22
#define NICHROME 32
#define X_STEP_PIN 2  // Pin for step signal (X-axis)
#define X_DIR_PIN 5   // Pin for direction signal (X-axis)
#define X_ENABLE_PIN 8 // Pin to enable/disable the motor
int dist = 5;
bool run = false;
void setup() {
  pinMode(X_STEP_PIN, OUTPUT);
  pinMode(X_DIR_PIN, OUTPUT);
  pinMode(X_ENABLE_PIN, OUTPUT); // Enable the motor (LOW to enable)
  digitalWrite(X_ENABLE_PIN, LOW); // Set direction of rotation
  digitalWrite(X_DIR_PIN, HIGH); // HIGH for one direction, LOW for the other
  pinMode(TRIG_PIN, OUTPUT);
  pinMode(ECHO_PIN, INPUT);
  pinMode(LED_33, OUTPUT);
  pinMode(LED_66, OUTPUT);
  pinMode(LED_FULL, OUTPUT);
  pinMode(NICHROME, OUTPUT);
  Serial.begin(9600);
}
long getDistance() {
    digitalWrite(TRIG_PIN, LOW);
    delayMicroseconds(2);
    digitalWrite(TRIG_PIN, HIGH);
    delayMicroseconds(10);
    digitalWrite(TRIG_PIN, LOW);
    long duration = pulseIn(ECHO_PIN, HIGH);
    long distance = duration * 0.034 / 2;  // Convert to cm
    return distance;
}


void runStepper(int distance)
{
  for (int i = 0; i < distance * 200; i++) { // Assuming 200 steps per revolution
            digitalWrite(X_STEP_PIN, HIGH);
            delayMicroseconds(1000); // Adjust speed by changing the delay
            digitalWrite(X_STEP_PIN, LOW);
            delayMicroseconds(1000);
        }
}


void loop() {
    long distance = getDistance();


    Serial.print("Distance: ");
    Serial.print(distance);
    Serial.println(" cm");


    // Turn on LEDs based on distance thresholds
    if(distance !=0){
      digitalWrite(LED_33, (distance <= 37) ? HIGH : LOW);
      digitalWrite(LED_66, (distance <= 29) ? HIGH : LOW);
      digitalWrite(LED_FULL, (distance <= 20) ? HIGH : LOW);
    }


    if ((distance < 20)&& (distance !=0)) {
        run = true;
        runStepper(dist);
        digitalWrite(NICHROME, HIGH);
        delay(10000);
        digitalWrite(X_DIR_PIN, !digitalRead(X_DIR_PIN));
        digitalWrite(NICHROME, LOW);
        runStepper(dist);
        digitalWrite(X_DIR_PIN, !digitalRead(X_DIR_PIN));
    }
}

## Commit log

2025-03-04 Added Submitted Report
    Smart Disposal Machine – Kriti 2025 Gold Medal Winning Project
    This repository contains the Smart Disposal Machine (SDM), an automated waste management system developed for Kriti 2025, the Inter-Hostel Technical Competition at IIT Guwahati. Our team won the Gold Medal in the Robotics category for designing a sensor-driven, IoT-enabled, and AI-integrated waste disposal system that optimizes hygiene, efficiency, and sustainability.
    ### Project Overview
    The Smart Disposal Machine is designed to automate waste disposal and segregation while reducing human intervention. It integrates ultrasonic sensors, microcontrollers, and automation mechanisms to monitor w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
2025-03-04 Added Code of bag deployment
    This code implements a BLDC motor control system for creating a vacuum mechanism in a smart dustbin. The vacuum helps in the self-deployment of plastic bags by pulling them into place. The system tak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
    The setup utilizes an ESC (Electronic Speed Controller) and an Arduino, with speed control managed through the Servo library.
2025-03-04 Added Code for Lid opening and closing
    This code implements a smart dustbin mechanism that automatically opens its lid using a servo motor when an object is detected within 10 cm by an ultrasonic sensor. Additionally, a BLDC fan is contro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
    The system utilizes an Arduino, a servo motor for lid movement, an ultrasonic sensor for distance measurement, and an ESC-controlled BLDC motor for the vacuum mechanism. The lid remains open for a se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
2025-03-04 Added Code for MQ3 and MQ4 gas sensors
    This code enables smell-based waste segregation using MQ3 and MQ4 gas sensors. The MQ3 sensor detects alcohol-based vapors, while the MQ4 sensor detects methane (CH₄) gas, helping in the identificati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
    The system continuously reads sensor values and sends the data to the Serial Monitor, allowing for real-time monitoring of gas concentrations. This data can be further processed to automate waste seg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
2025-03-04 Added Code for Level Detection and CNC Control
    This Arduino-based Level Detection and CNC Control Code integrates ultrasonic sensing, LED indicators, nichrome wire activation, and stepper motor control for automated material handling.
    Key Features:
    ✔ Ultrasonic Sensor (HC-SR04): Measures distance to detect material level in a container.
    ✔ LED Indicators: Three LEDs (33%, 66%, and Full) provide a visual indication of the fill level.
    ✔ Nichrome Wire Activation: Triggers a heating element when the material reaches a critical level.
    ✔ Stepper Motor Control (CNC Mechanism): Moves an actuator based on detected level using an X-axis stepper motor.
    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
2025-03-04 Added the Main Code
    This Arduino-powered Automated Processing and Control System integrates lid automation, material level monitoring, gas detection, heating activation, and motorized processing for efficient operation 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
    ✔ Automated Lid Mechanism: Controls a servo-driven lid based on ultrasonic sensor feedback.
    ✔ Material Level Monitoring: Uses distance sensing to track material levels and trigger processing.
    ✔ Gas Detection System: MQ3 and MQ4 sensors identify specific gases for safety and control.
    ✔ Nichrome Wire Heating: Activates a heating element via a relay for precise thermal processing.
    ✔ Stepper Mo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
2025-03-05 Added the CAD files
    The CAD files showcase the structural and functional design of the dustbin, ensuring a practical and scalable implementation.
    [Assem1.SLDASM, Draw13.SLDDRW, Draw2.SLDDRW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]
